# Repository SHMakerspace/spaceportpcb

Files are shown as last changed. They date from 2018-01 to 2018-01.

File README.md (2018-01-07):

Spaceport PCBs
============
This repos is the 2 PCBs which make up the client portion of [Spaceport](https://github.com/SHMakerspace/spaceport). This consists of the **Spaceport Controller** and the **Spaceport reader**.

Design has been created in EagleCAD.

![PCBs](https://lh3.googleusercontent.com/g8-eCmGsM58siEUREAJQxgl26oSliJ-2NyPW6FOMdzvt_YHkEdBsc1cU5JWBC_lprGO7F8F3ThcDM_IRJHGNp3lH1DRBhw5yG0vpXb5wSVXzZ42BomTwUZnGATMCjlY0k3_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)

Instructions and more information on Spaceport can be found in the [Spaceport repo](https://github.com/SHMakerspace/spaceport).

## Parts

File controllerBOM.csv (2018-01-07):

Qty | Value | Device | Package | Parts | Description | MF | MPN | OC_FARNELL | OC_NEWARK
1 |  | 10-XX | B3F-10XX | S1 | OMRON SWITCH |  | B3F-1000 | 176432 | 36M3542
1 |  | LED3MM | LED3MM | LED1 | LED
2 |  | PINHD-1X2 | 1X02 | JP2, JP5 | PIN HEADER
2 |  | PINHD-1X3CB | 1X03-CLEANBIG | JP1, JP3 | PIN HEADER
1 |  | PINHD-1X4 | 1X04 | JP4 | PIN HEADER
1 | 0 | R-EU_0204/5 | 0204/5 | R5 | RESISTOR, European symbol
1 | 0.1uf | C-EU050-024X044 | C050-024X044 | C2 | CAPACITOR, European symbol
1 | 0.33uf | C-EU050-024X044 | C050-024X044 | C1 | CAPACITOR, European symbol
3 | 10k | R-EU_0204/5 | 0204/5 | R1, R2, R4 | RESISTOR, European symbol
1 | 1N4004 | 1N4004 | DO41-10 | D1 | DIODE
2 | 2.1MMJACKTHM | 2.1MMJACKTHM | PJ-102A | U$5, U$8 | 2.1mm x 5.5mm THM DC jack with internal switch. Digikey part #PJ-102A, 4UCON part #05537
1 | 300R | R-EU_0204/5 | 0204/5 | R6 | RESISTOR, European symbol
1 | 330R | R-EU_0204/5 | 0204/5 | R3 | RESISTOR, European symbol
1 | 7805TV | 7805TV | TO220V | IC1 | Positive VOLTAGE REGULATOR
2 | NTD4963NT0220 | NTD4963NT0220 | T0220 | IC2, IC3
1 | RFID-RC522NOHOLES | RFID-RC522NOHOLES | RFID-RC522-NOHOLES | U$14
2 | RJ45-RDF | RJ45-RDF | RJ45-RDF | X1, X2
1 | WEMOS | WEMOS | WEMOS | U$1

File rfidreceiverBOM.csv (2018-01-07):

Qty | Value | Device | Package | Parts | Description
1 |  | PINHD-1X3CB | 1X03-CLEANBIG | JP1 | PIN HEADER
2 | 0.1uf | C-EU050-024X044 | C050-024X044 | C2, C4 | CAPACITOR, European symbol
2 | 0.33uf | C-EU050-024X044 | C050-024X044 | C1, C3 | CAPACITOR, European symbol
1 | 300R | R-EU_0204/5 | 0204/5 | R1 | RESISTOR, European symbol
1 | 7805TV | 7805TV | TO220V | IC2 | Positive VOLTAGE REGULATOR
1 | L78L33 | MCP1700L78L33PINS | TO92-INLINE | IC1 | VOLTAGE REGULATOR
1 | RFID-RC522 | RFID-RC522 | RFID-RC522 | U$2
1 | RJ45-RDF | RJ45-RDF | RJ45-RDF | X1

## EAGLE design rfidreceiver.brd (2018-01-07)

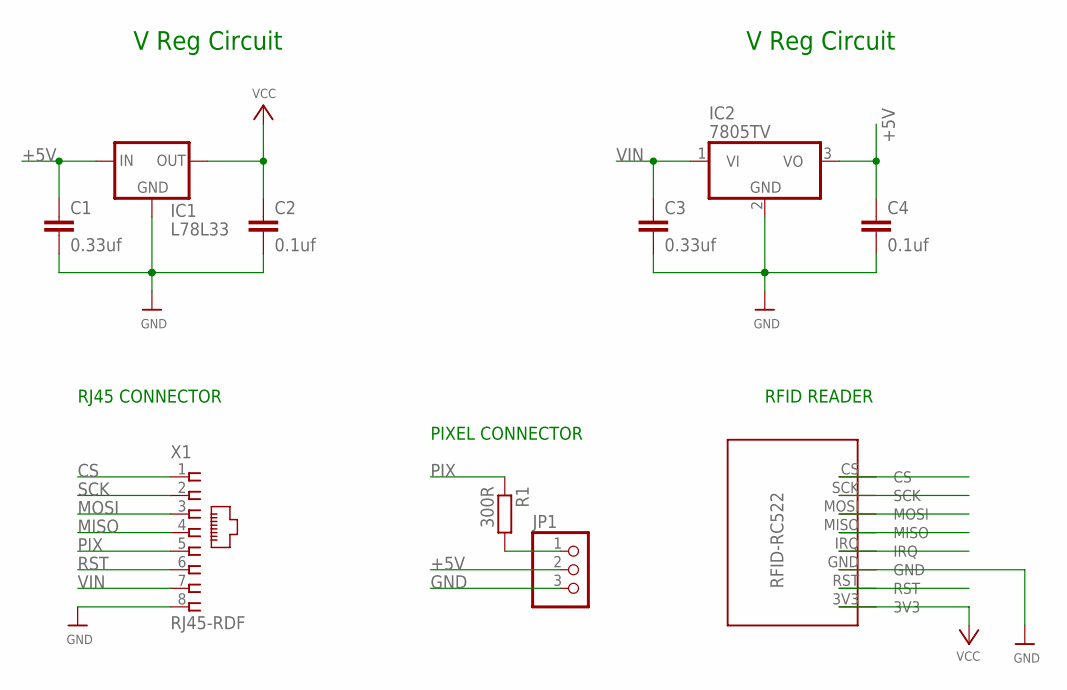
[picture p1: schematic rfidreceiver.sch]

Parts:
C1, C3: 0.33uf; C050-024X044
C2, C4: 0.1uf; C050-024X044
IC1: L78L33; TO92-INLINE
IC2: 7805TV; TO220V
JP1: PINHD-1X3CB; 1X03-CLEANBIG
R1: 300R; 0204/5
U$2: RFID-RC522
X1: RJ45-RDF

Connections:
+5V: C1.1, C4.1, IC1.1 (IN), IC2.3 (VO), JP1.2
CS: U$2.CS, X1.1
GND: C1.2, C2.2, C3.2, C4.2, IC1.2 (GND), IC2.2 (GND), JP1.3, U$2.GND, X1.8
IRQ: U$2.IRQ
MISO: U$2.MISO, X1.4
MOSI: U$2.MOSI, X1.3
unnamed: JP1.1, R1.2
PIX: R1.1, X1.5
RST: U$2.RST, X1.6
SCK: U$2.SCK, X1.2
VCC: C2.1, IC1.3 (OUT), U$2.3V3
VIN: C3.1, IC2.1 (VI), X1.7

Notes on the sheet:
V Reg Circuit
PIXEL CONNECTOR
RFID READER
RJ45 CONNECTOR

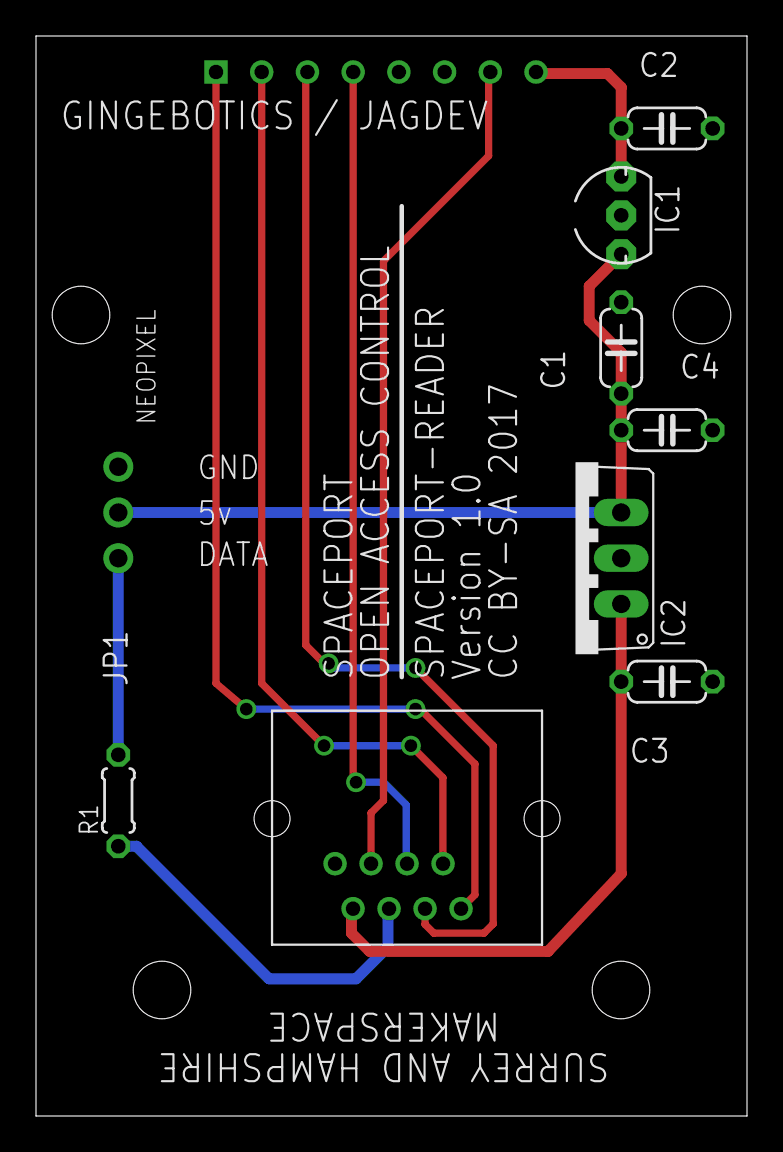
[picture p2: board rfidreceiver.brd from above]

Board: 2 copper layers, 39.5 x 60.0 mm, 10 parts (1 on the bottom side), 11 nets.

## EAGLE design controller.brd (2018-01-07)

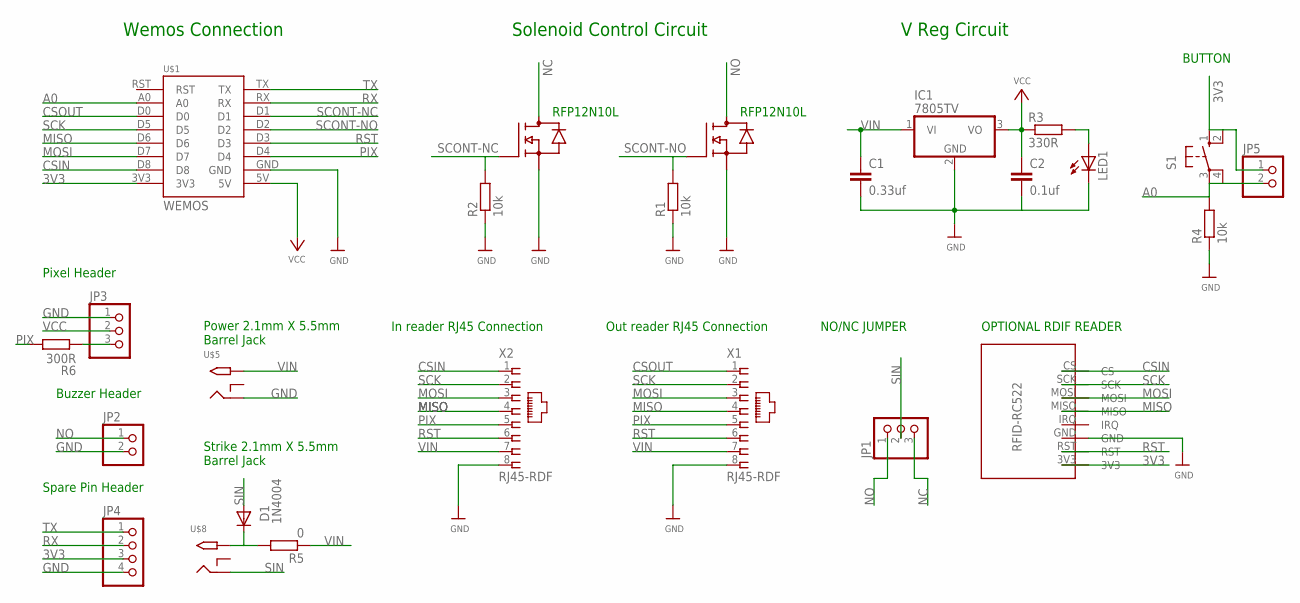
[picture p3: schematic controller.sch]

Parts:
C1: 0.33uf; C050-024X044
C2: 0.1uf; C050-024X044
D1: 1N4004; DO41-10
IC1: 7805TV; TO220V
IC2, IC3: NTD4963NT0220; T0220
JP1, JP3: PINHD-1X3CB; 1X03-CLEANBIG
JP2, JP5: PINHD-1X2; 1X02
JP4: PINHD-1X4; 1X04
LED1: LED3MM
R1, R2, R4: 10k; 0204/5
R3: 330R; 0204/5
R5: 0; 0204/5
R6: 300R; 0204/5
S1: 10-XX; B3F-10XX
U$1: WEMOS
U$5, U$8: 2.1MMJACKTHM; PJ-102A
U$14: RFID-RC522NOHOLES; RFID-RC522-NOHOLES
X1, X2: RJ45-RDF

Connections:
3V3: JP4.3, JP5.1, S1.1 (S), S1.2 (S1), U$1.3V3, U$14.3V3
A0: JP5.2, R4.2, S1.3, S1.4 (P1), U$1.A0
CSIN: U$1.D8, U$14.CS, X2.1
CSOUT: U$1.D0, X1.1
GND: C1.2, C2.2, IC1.2 (GND), IC2.3 (S), IC3.3 (S), JP2.2, JP3.1, JP4.4, LED1.K (C), R1.1, R2.1, R4.1, U$1.GND, U$5.RING, X1.8, X2.8
MISO: U$1.D6, U$14.MISO, X1.4, X2.4
MOSI: U$1.D7, U$14.MOSI, X1.3, X2.3
unnamed: D1.C, R5.2, U$8.TIP
unnamed: JP3.3, R6.1
unnamed: LED1.A, R3.2
NC: IC2.2 (D), JP1.3
NO: IC3.2 (D), JP1.1, JP2.1
PIX: R6.2, U$1.D4, X1.5, X2.5
RST: U$1.D3, U$14.RST, X1.6, X2.6
RX: JP4.2, U$1.RX
SCK: U$1.D5, U$14.SCK, X1.2, X2.2
SCONT-NC: IC2.1 (G), R2.2, U$1.D1
SCONT-NO: IC3.1 (G), R1.2, U$1.D2
SIN: D1.A, JP1.2, U$8.RING
TX: JP4.1, U$1.TX
VCC: C2.1, IC1.3 (VO), JP3.2, R3.1, U$1.5V
VIN: C1.1, IC1.1 (VI), R5.1, U$5.TIP, X1.7, X2.7

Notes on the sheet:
V Reg Circuit
Wemos Connection
Solenoid Control Circuit
Power 2.1mm X 5.5mm Barrel Jack
In reader RJ45 Connection
Out reader RJ45 Connection
NO/NC JUMPER
Strike 2.1mm X 5.5mm Barrel Jack
Buzzer Header
Spare Pin Header
RFP12N10L
Pixel Header
OPTIONAL RDIF READER
BUTTON

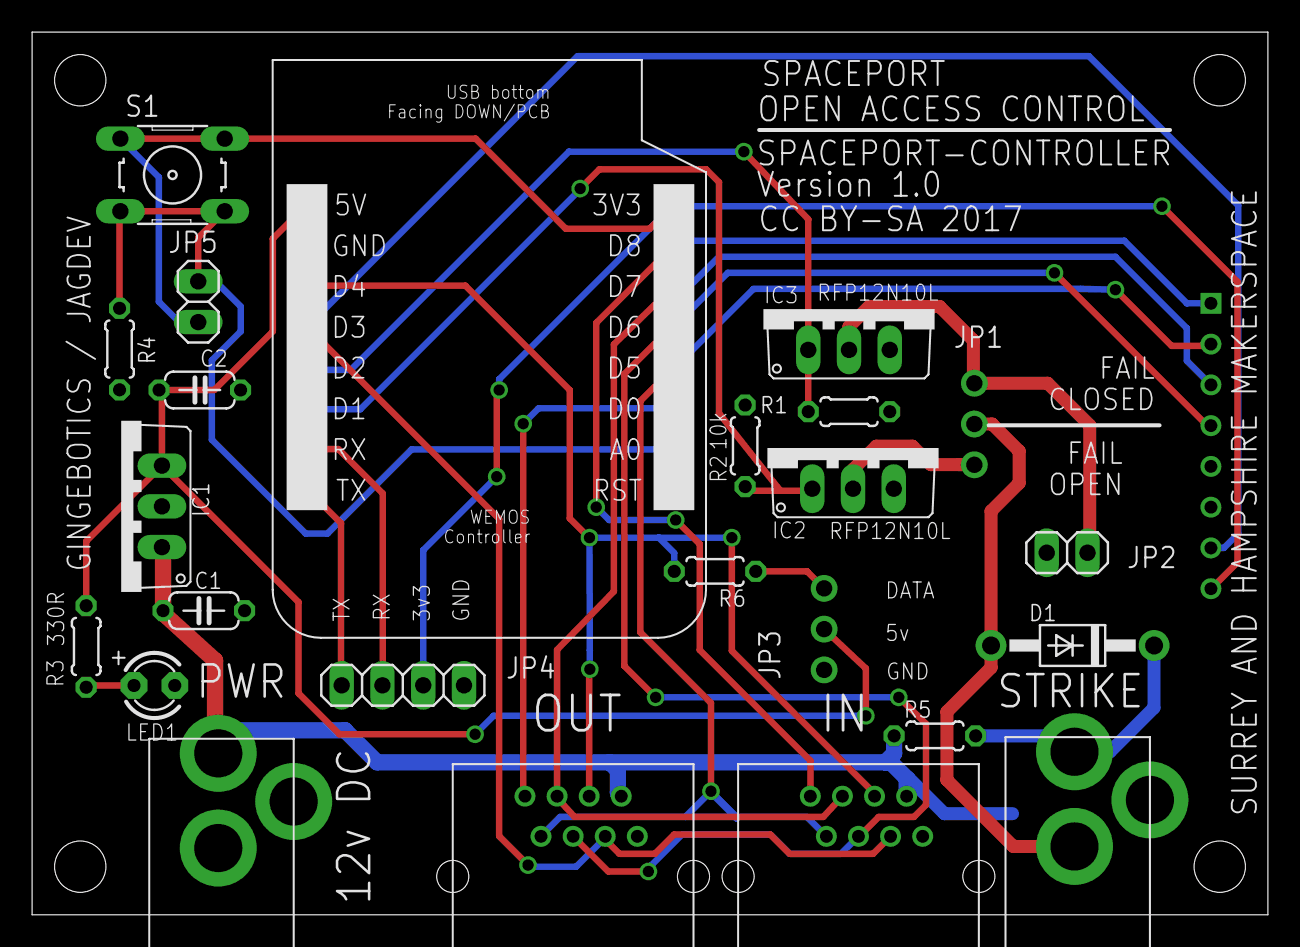
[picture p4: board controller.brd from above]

Board: 2 copper layers, 77.0 x 55.0 mm, 25 parts (1 on the bottom side), 22 nets.

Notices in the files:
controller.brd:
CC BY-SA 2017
